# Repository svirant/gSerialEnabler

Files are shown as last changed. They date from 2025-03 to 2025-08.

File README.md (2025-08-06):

# gSerial Enabler
**"plug-n-play" gcomp/gscart EXT adapter that enables auto-profiles for the RetroTink 4K**

 - A powered-on console on port 1-8 will load SVS profiles S201_ - S208_ on the RT4K Pro/CE
 - Compatible with the SVS
 - Connect multiple gSerial Enablers, Donut Holes, Donut Dongles simultaneously via a headphone jack splitter.
   - Must reflash "firmware" with offset variable set so SVS profile numbers don't overlap.
   - Ex: offset = 8, adds 8 to the default of 201. So ports 1 - 8 would now be S209_ - S216_
   - Up to 5 have been connected together simultaneously. More may be supported, but this is the max number I've been able to test.
 - Full instructions listed below for building your own!
 - If DIY is not your thing, I also have a handful assembled and available for purchase on [Ko-fi](https://ko-fi.com/donutswdad/shop)

> [!NOTE]
> The EXT port does not exist on all gscart/gcomp revisions. Make sure your switch has one! There are now 2 versions available.
>  - "Internal" is for EXT with no header. (exposed through-holes)
>  - "External" is for EXT with right angle header populating the port.
</br>

Thanks to Bob [@RetroRGB](https://www.retrorgb.com/) for showcasing!</br>
Thanks Bob (https://www.youtube.com/watch?v=3wcF-8wC7H4&t=119s)
Thanks Bob (https://www.youtube.com/watch?v=b-BxFDCHc2k&t=1107s)

# Internal
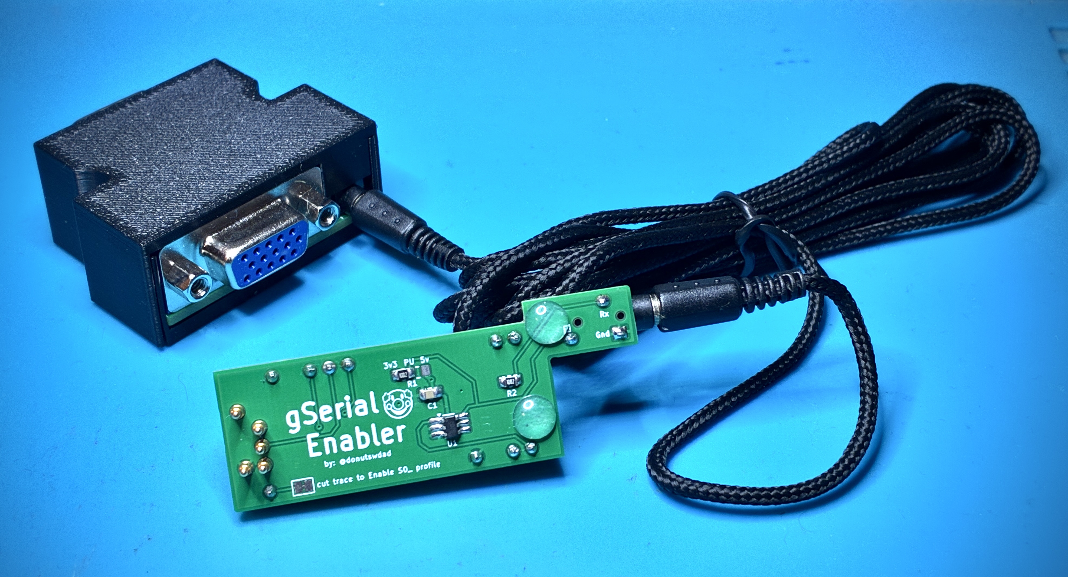
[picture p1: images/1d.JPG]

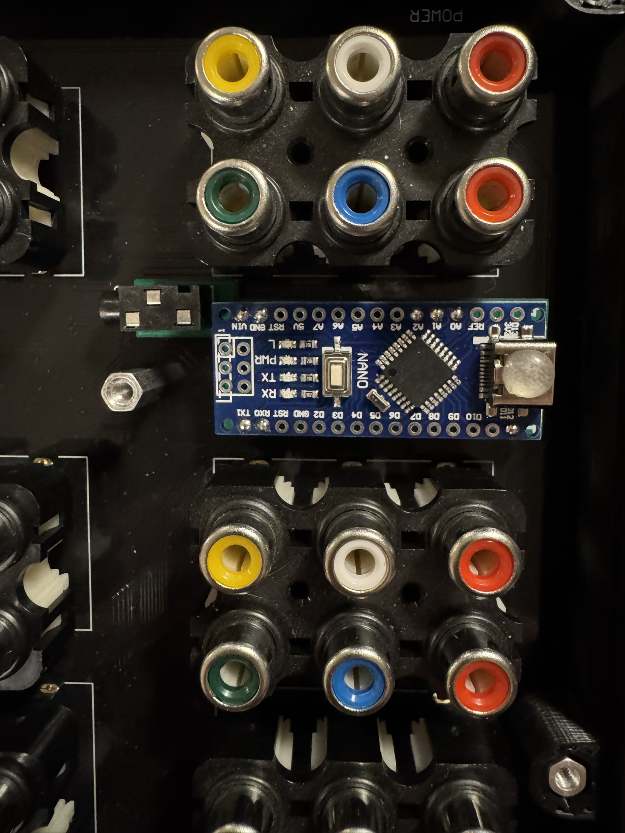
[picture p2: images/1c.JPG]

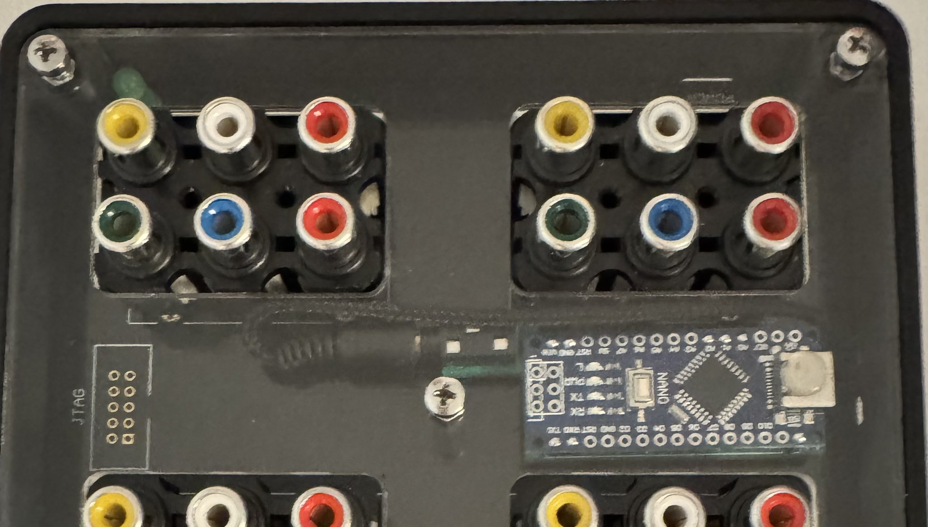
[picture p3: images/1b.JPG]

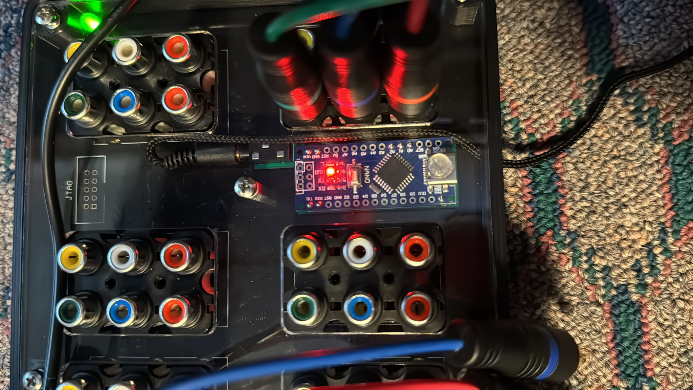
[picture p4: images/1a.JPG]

<br />
<br />

# External
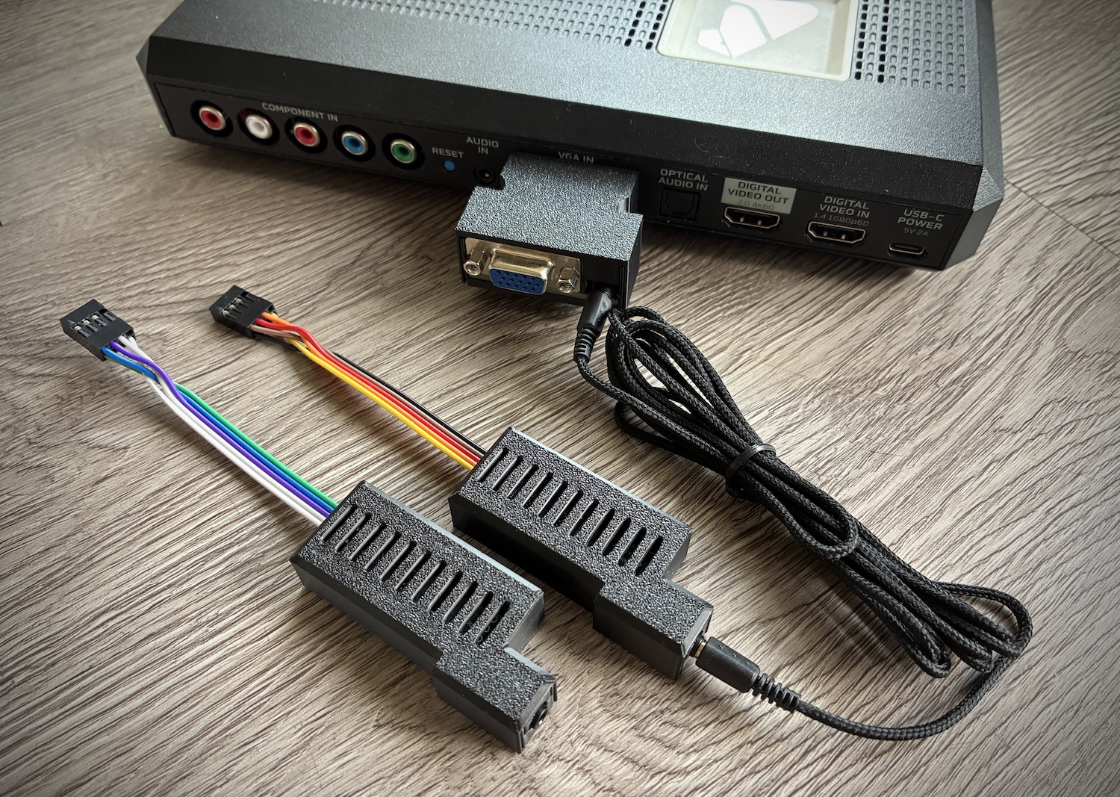
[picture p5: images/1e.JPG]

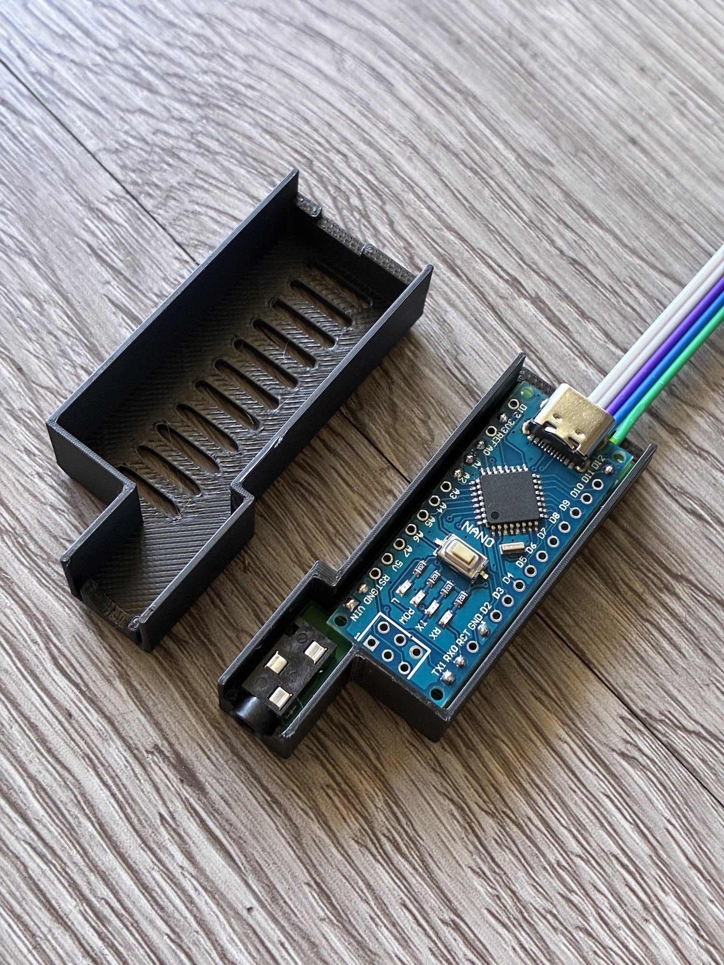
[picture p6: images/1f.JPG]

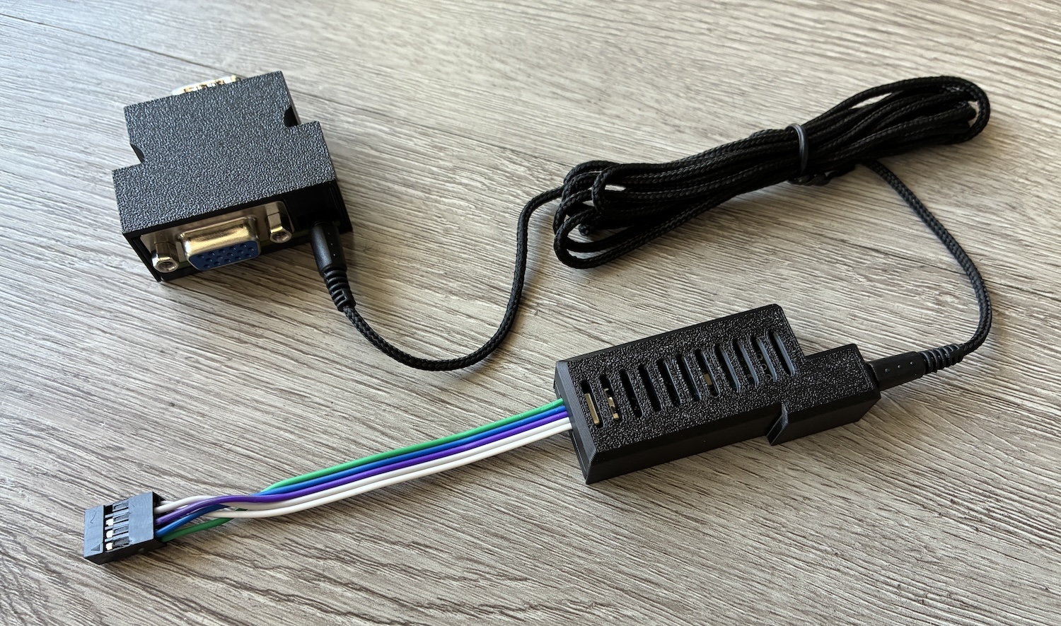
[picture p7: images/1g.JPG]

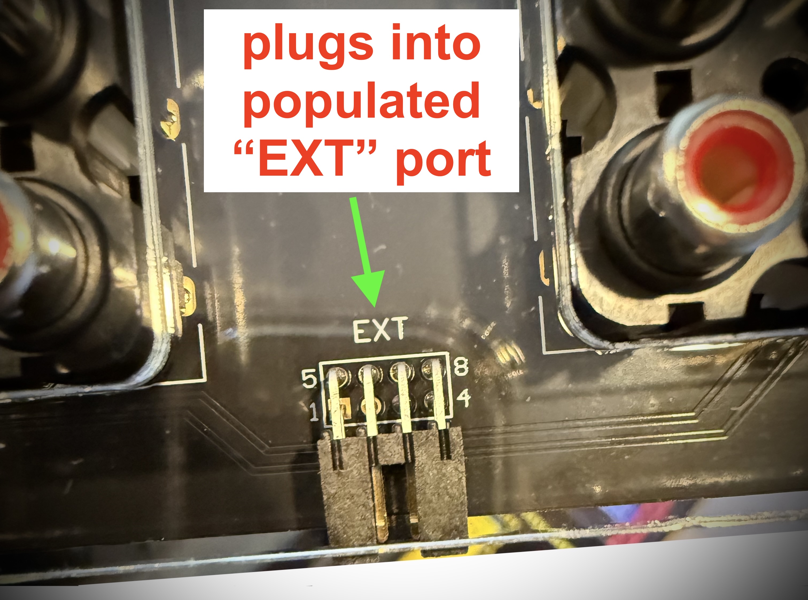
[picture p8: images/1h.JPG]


# Conversion!
> [!TIP]
>  - If you wanted to use the External version on your headerless gcomp/gscart, you can easily solder a 2.54mm DC3 angled header onto the EXT port. Part listed in BOM below.
</br>

# Thanks to 
   - **[@UstSte](https://x.com/UstSte) for the photos and testing.**

   - **[Bob](https://twitter.com/retrorgb) @ [RetroRGB](https://www.retrorgb.com/retrotink-4k-firmware-v1-6-9-released.html) for his ideas and continued support.**

<br />
<br />

# Ordering PCBs
PCBs for this project:
 - [gSerial Enabler (Internal)](https://github.com/svirant/gSerialEnabler/blob/main/gSerial_Enabler.zip)
 - [gSerial Enabler (External)](https://github.com/svirant/gSerialEnabler/blob/main/gSerial_Enabler_External.zip)
    - [3DP Case (External)](https://github.com/svirant/gSerialEnabler/blob/main/gSerial_Enabler.3mf)
 - [VGA Adapter](https://github.com/svirant/DonutDongle/tree/main/Adapters) (VGAPassthrough or YC2VGA)
</br>

> [!NOTE]
> The "Internal" PCB can also be used for the "External" build. Only the through-holes are smaller. The through-holes have been made larger on the External version to make soldering the Dupont line easier.
> It should be noted that the reverse is not true. The through-holes on the External version are too big to properly secure to pogo-pins.
>

</br>

There are plenty of options for PCB manufacturing but I prefer [JLCPCB](https://jlcpcb.com) (No affiliation). Using the gerber (.zip) files provided, it's easy to place an order. Below are some tips/guidelines:
- 1.6mm Thickness
- For Surface Finish, "HASL(with lead)" is fine
- 4 Layer PCBs are the same cost as 2 Layer for the VGA Adapters. Because of that, the inner 2 layers are being used as ground planes for better EMI protection. Thanks to https://x.com/zaxour for the idea!
- "Remove Mark" option is now free on JLCPCB. Use it!
- All remaining default options should be fine
- Let me know if you have any questions!

# Assembly

[Interactive HTML BOM](https://svirant.github.io/gSerialEnabler/images/ibom.html)

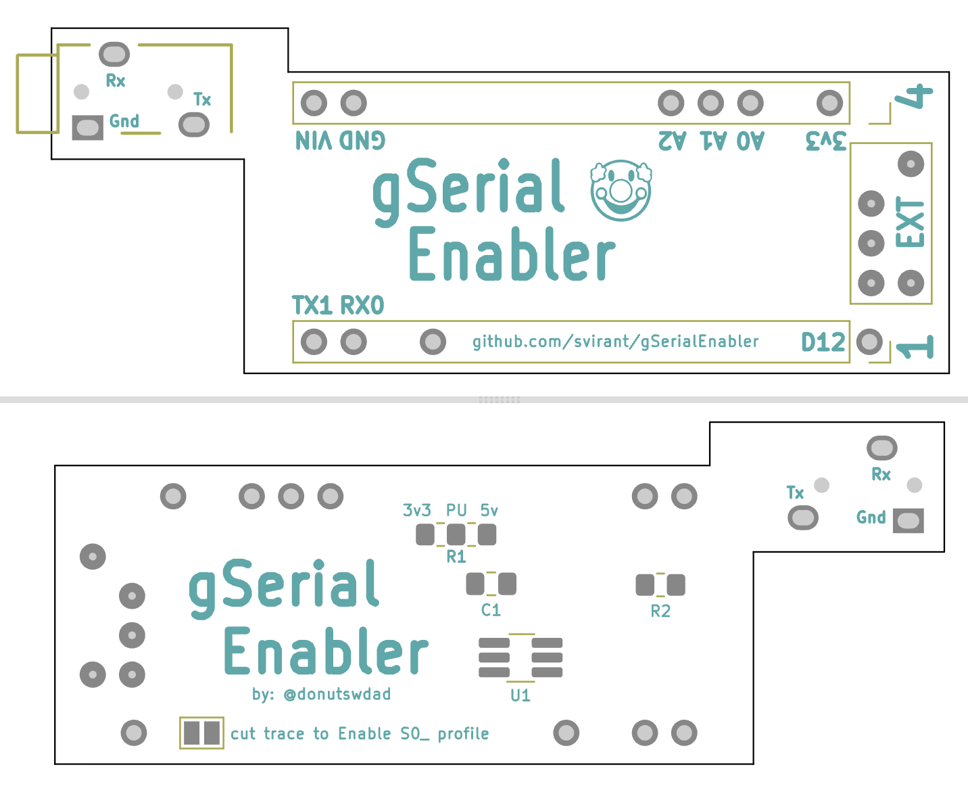
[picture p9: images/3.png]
[](https://svirant.github.io/gSerialEnabler/images/ibom.html)

## Internal assembly
In addition to the top of the usb-c port, place two more 6x2mm rubber feet to the spots shown, to secure the PCB.

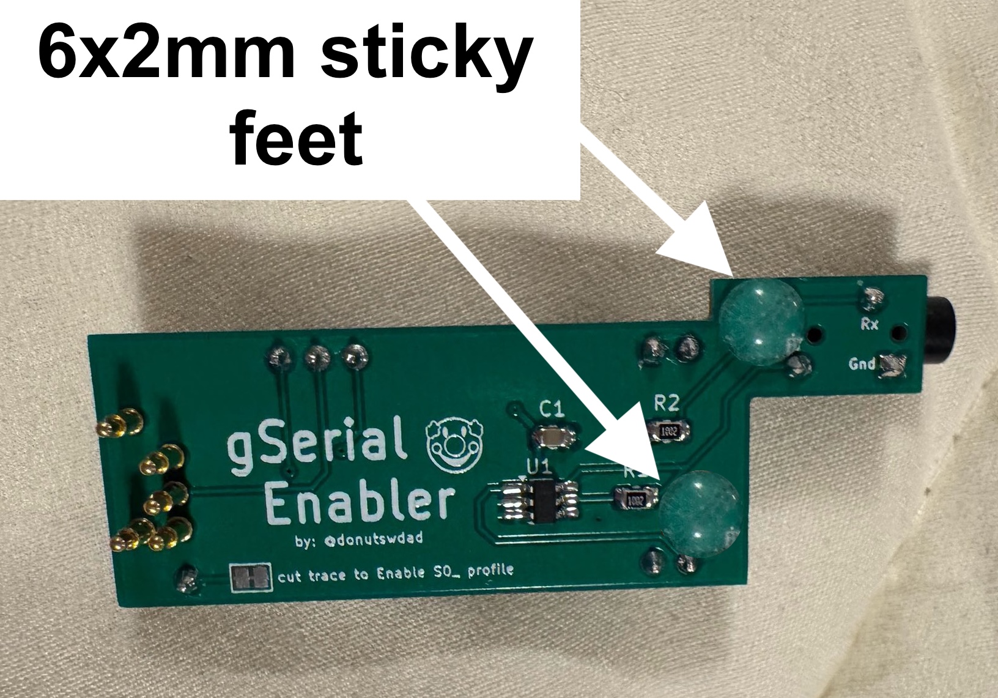
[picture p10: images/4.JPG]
 </br>

## External assembly
 - Cut Dupont line in half for 10cm section. 
 - Remove plastic covers on Dupont line and insert into 2x4 Dupont shell as shown below.
 - Strip wire on other end and solder into through-holes on PCB.

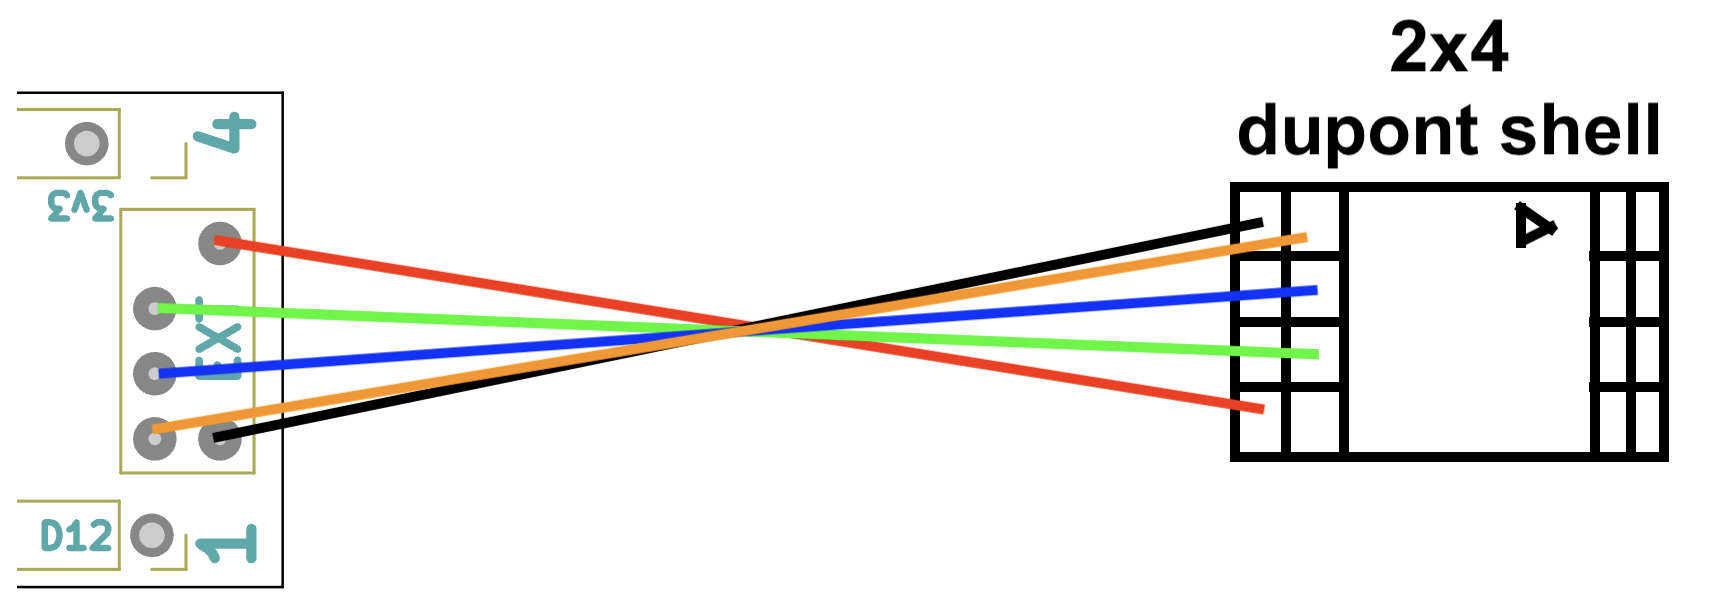
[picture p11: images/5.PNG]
 </br>

# PCB
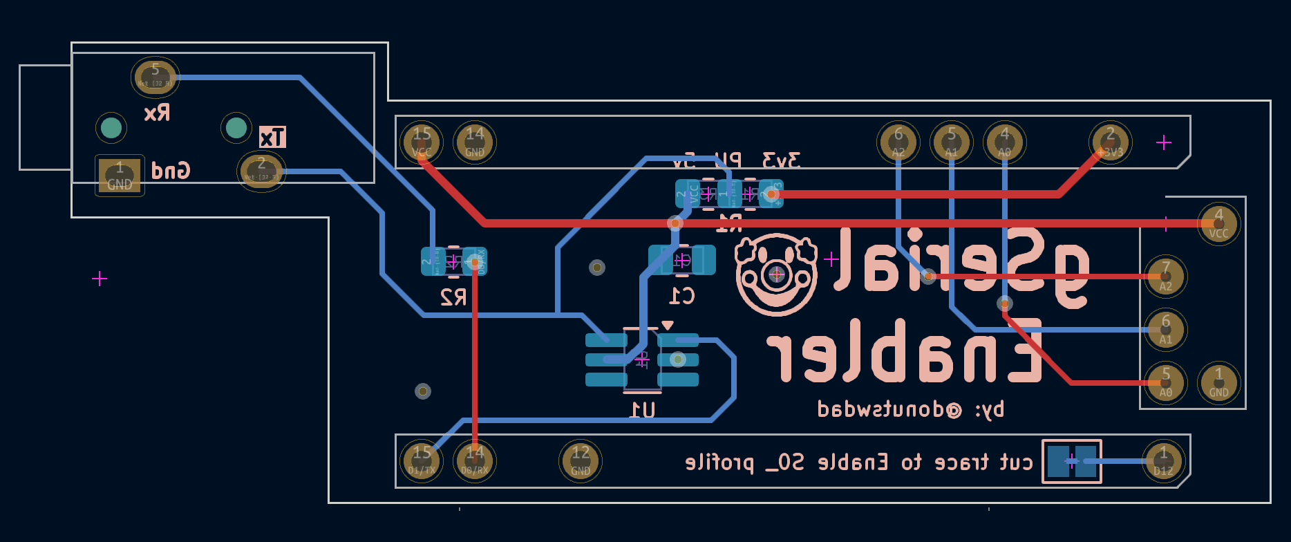
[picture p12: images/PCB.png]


# Schematic
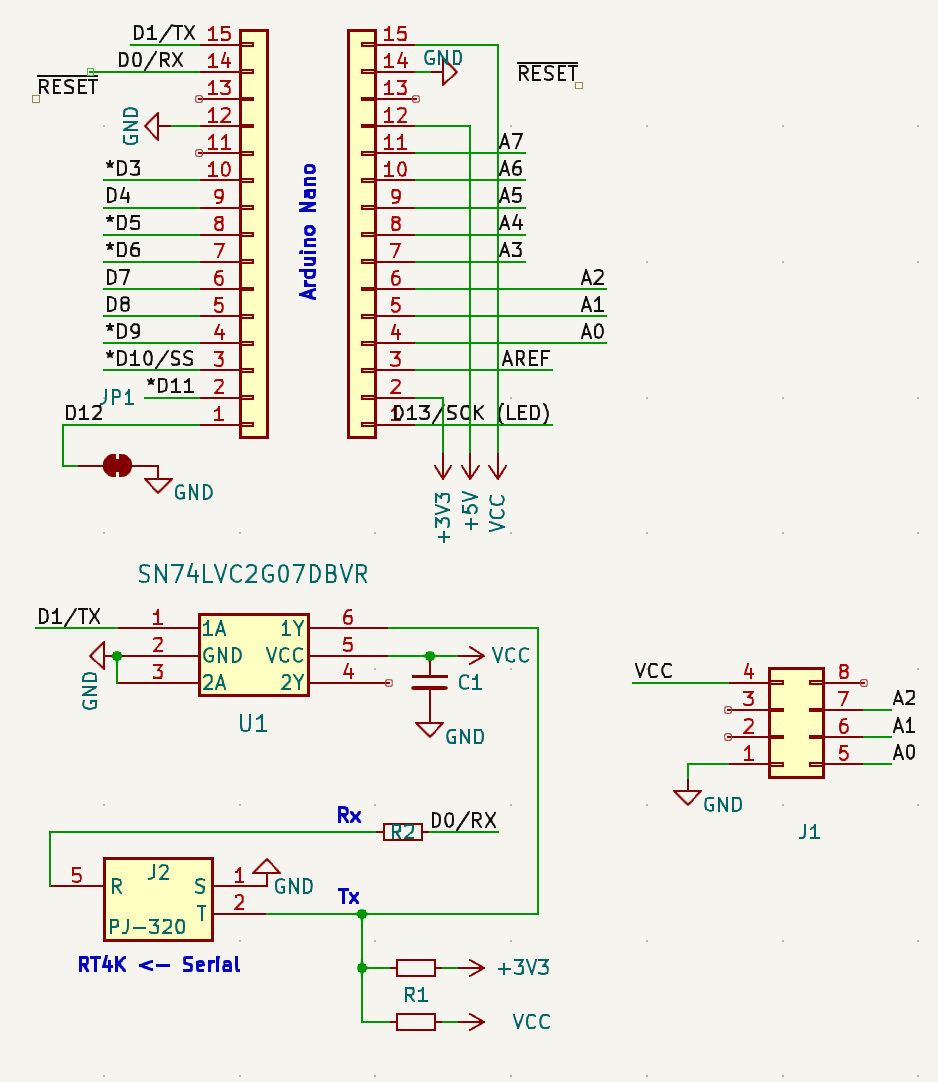
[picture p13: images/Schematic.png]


## Bill of Materials (BOM)

### * gSerial Enabler
| **Qty** | Designation | Part |  Link  |  Notes |
| --- | --- |--- |--- |--- |
| 1  | C1 | 0.1 uf / 100nf 50V X7R 0805 Capacitor| [Digikey](https://www.digikey.com/en/products/detail/yageo/CC0805KRX7R9BB104/302874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) | |
| 2  | R1, R2 | 10K OHM 1% 1/8W 0805 Resistor | [Digikey](https://www.digikey.com/en/products/detail/yageo/AC0805FR-0710KL/2827834) | |
| 1  | U1 | IC BUF NON-INVERT 5.5V SOT23-6 | [Digikey](https://www.digikey.com/en/products/detail/texas-instruments/SN74LVC2G07DBVR/486427) or [alternate](https://www.digikey.com/en/products/detail/umw/SN74LVC2G07DBVR/24889644) | |
| 1  | J2 | PJ-320 3.5MM Headphone Jack Audio Video Female | [AliExpress](https://www.aliexpress.us/item/3256807448104402.html) | Color: PJ-320B DIP | 
| 10  | J3,J4 | 2.54mm male pin headers | break off the male headers that come with the Arduino Nano | | 
| 1  | | Arduino Nano type c | Support [RetroRGB!](https://amzn.to/4gnHqN4) | Make sure the headers are not soldered. |
| 1  | | Any 3.5mm / aux / stereo / trs / cable | [AliExpress](https://www.aliexpress.us/item/2255799962255486.html) | I prefer the one listed because the cable itself is very flexible and has no problem being routed inside the case.|
| 1  | | usb-c cable for Arduino programming | [AliExpress](https://www.aliexpress.us/item/3256806983355947.html) | |
| 3 | | 6x2mm sticky rubber feet | [Amazon](https://www.amazon.com/dp/B06XCNM69B)| Internal version only |
| 5 | Pogo-Pin | Mill-Max 0906-1-15-20-75-14-11-0 | [Digikey](https://www.digikey.com/en/products/detail/mill-max-manufacturing-corp/0906-1-15-20-75-14-11-0/1147049) | Internal version only |
| 1 | 2x4 Dupont shell | Pins: 2x4Pin | [AliExpress](https://www.aliexpress.us/item/2255800942949805.html) | External version only | 
| 1 | Dupont line 20cm | Color: Female to Female | [AliExpress](https://www.aliexpress.us/item/3256805315188857.html) | External version only |
| 1 | CONN HEADER R/A 8POS 2.54MM | Part# 78207-108HLF | [Digikey](https://www.digikey.com/en/products/detail/amphenol-cs-fci/78207-108HLF/1002752) | (Optional) If you wanted to use the External version on your headerless gcomp/gscart, you can solder this part on. |
| 1 | Alt to the official header above | Color: Right Angle Type , Pins: 8P | [AliExpress](https://www.aliexpress.us/item/3256805058042964.html) | Will most likely not fit inside the LaserBear bumper case, not confirmed. Just FYI. |

### * VGA Adapter assembly and BOM can be found [here](https://github.com/svirant/DonutDongle?tab=readme-ov-file#at-least-1-of-the-following-vga-adapters-is-required)
<br />

# Programming an Arduino Nano
I recommend the [Official Arduino IDE and guide](https://www.arduino.cc/en/Guide) if you're unfamiliar with Arduinos. All .ino files used for programming are listed above. 

Some Arduino Nanos come with an Old Bootloader and won't Upload unless specified. **If you get errors** when trying to upload, swap to this option as a possible fix.

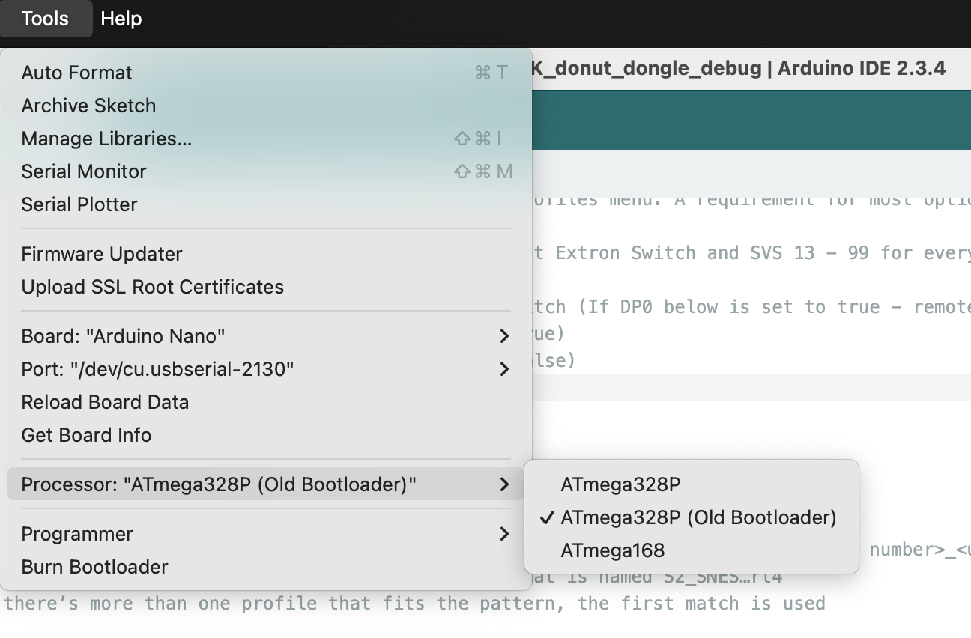
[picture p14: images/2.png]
bootloader


## Steps to update offset
 - 1 - Download and install the [Arduino IDE](https://www.arduino.cc/en/software/) for your PC or Mac
 - 2 - Click the green "<> Code" button above and "Download ZIP".
 - 3 - Extract the .zip file and open up the "gSerial_Enabler.ino" file in the Arduino IDE. It will ask if you would like to move this file inside a folder, select OK.
 - 4 - With the source code now open, select "Tools" -> "Board" -> "Arduino AVR Boards" -> "Arduino Nano"
 - 5 - Connect the gSerial Enabler device to your PC or Mac using a usb-c cable. You should see an LED light up when connected.
   - If connecting the "External" version, you must remove the top half of the case by sliding it upwards while holding parts beneath the aux jack on one side and ribbon cable on other. This will expose the usb-c port.
   - If connecting the "Internal" version, it's okay to flash it while still inside the gscart/gcomp. Just disconnect power from the gscart/gcomp first.
 - 6 - With the gSerial Enabler now connected, select it's "port" by going to "Tools" -> "Port", and select the port that starts with "/dev/cu.usbserial-" (on Mac) or "COM" if on PC.
 - 7 - Almost done! :) In the code itself, find the line that starts with "uint16_t const offset = 0;" and change the 0 to an 8. It should now look like this: uint16_t const offset = 8;
   - At the moment this is line 27
 - 8 - From the menu at the top, select "Sketch" -> "Upload". You should see the LEDs on the Arduino Nano flicker and a message that says "Done uploading." if successful.
    - If you get errors, see the section above about changing the "Bootloader" type.
 - 9 - Disconnect the usb-c cable and give it a whirl! You can repeat these steps in the future to make any other changes or update if a newer firmware is ever released.
  -----------
# How to Use
- Make sure **"Auto Load SVS"** is **"On"** under the RT4K Profiles menu.  
- The RT4K checks the **/profile/SVS** subfolder for profiles and need to be named: **S\<input number>_\<user defined>.rt4**  For example, SVS input 201 would look for a profile that is named S201_SNES.rt4.  If there’s more than one profile that fits the pattern, the first match is used.

- Check the RT4K Diagnostic Console for Serial commands being received as confirmation.

## SVS Profile numbering scheme

**Ports 1-8 = S201\_ - S208\_**

The "offset" option can be used if using multiple gSerial Enablers connected to the RT4K via a headphone splitter. If using a 2nd, change to "offset = 8" for the 2nd to be SVS profiles 209 - 216.

```
uint16_t const offset = 0; // Only needed for multiple gSerial Enablers. Set offset so 2nd, 3rd, etc gSEs don't overlap profiles. (e.g. offset = 8;) 
```

## S0_ profile Enable

By cutting the trace on the PCB, you can enable the S0_ profile which will load S0_\<whatever\>.rt4 when all inputs are off. If you wish to revert the change, you can bridge the trace with a solder blob. 

Instead of cutting the trace, you can also change line 29 of the gSerial_Enalber.ino to "true" for the same functionality. ...Assuming you are able to program the Arduino Nano with the updated .ino. Up to you which method to choose.

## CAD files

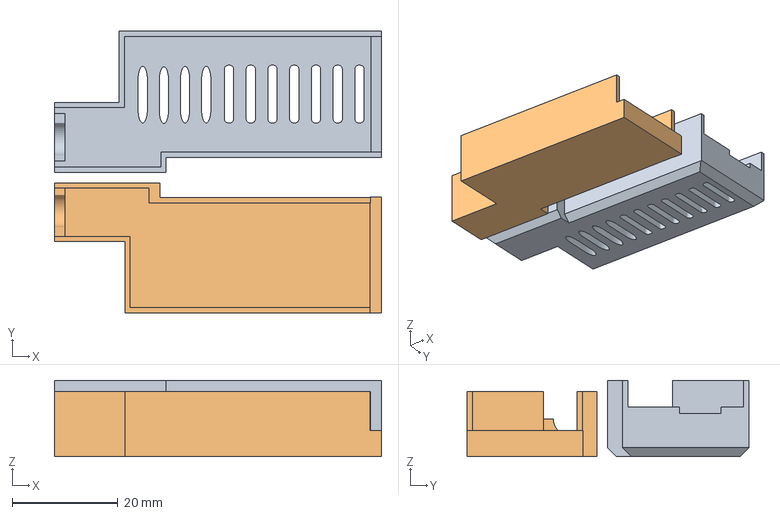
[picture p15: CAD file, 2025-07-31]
gSerial_Enabler.3mf
61.8 x 53.3 x 14.4 mm
gSerialEnabler_T2.stl
gSerialEnabler_Bottom.stl

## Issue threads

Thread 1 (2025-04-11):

Chance for Extron Crosspoint Ultra Version?

aaaaafuck, 2025-04-11:
Is there any chance we can see a version of this that works with an Extron Crosspoint Ultra as apposed to the Gswitches? I believe they have some sort of serial adapter on the rear of the unit, but I could be wrong as to what that is for. There may also be a way to use the lan port to determine what preset is selected.

svirant, 2025-04-11:
Howdy! There are 2 projects I have that can talk to a handful of Extron switches and even TESmart/MK-VIKI HDMI switches.

[Donut Dongle](https://github.com/svirant/DonutDongle)
[Donut Hole](https://github.com/svirant/DonutHole)

There are currently some Donut Dongles made by another user for sale on the RetroTink Discord Classified section.  I don't have any plans to make these as they are very time consuming, but I do plan on making some of the "Donut Hole" devices soon...

Closed 2025-04-11.

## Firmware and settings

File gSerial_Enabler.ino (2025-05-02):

/*
* gSerial Enabler v0.4
* Copyright (C) 2025 @Donutswdad
*
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
* You should have received a copy of the GNU General Public License
* along with this program.  If not, see <http://www.gnu.org/licenses/>.
*/

/*
////////////////////
//    OPTIONS    //
//////////////////
*/

uint8_t debugG = 0; // line ~180

uint16_t const offset = 0; // Only needed if multiple Donut Holes, gSerial Enablers, Donut Dongles are connected. Set offset so 2nd, 3rd, etc don't overlap profiles. (e.g. offset = 8;) 

bool S0 = false;           // (Profile 0) 
                           //  ** Recommended to leave this option "false" if using in tandem with other Serial devices. ** (Leave JP1 trace un-cut)

////////////////////
                       
// gscart / gcomp adjustment variables for port detection
float const highsamvolt = 2.4; // rise above this voltage for a high sample
byte const apin[3] = {A0,A1,A2}; // defines analog pins used to read bit0, bit1, bit2 respectively
uint8_t const dch = 15; // (duty cycle high) at least this many high samples per "samsize" for a high bit (~75% duty cycle)
uint8_t const dcl = 5; // (duty cycle low) at least this many high samples and less than "dch" per "samsize" indicate all inputs are in-active (~50% duty cycle)
uint8_t const samsize = 20; // total number of ADC samples required to capture at least 1 period
uint8_t const fpdccountmax = 3; // number of periods required when in the 50% duty cycle state before a Profile 0 is triggered.


// gscart / gcomp Global variables
uint8_t fpdcprev = 0; // stores 50% duty cycle detection
uint8_t fpdccount = 0; // number of times a 50% duty cycle period has been detected
uint8_t allgscartoff = 2; // 0 = at least 1 port is active, 1 = no ports are active, 2 = disconnected or not used yet
uint8_t samcc = 0; // ADC sample cycle counter
uint8_t highcount[3] = {0,0,0}; // number of high samples recorded for bit0, bit1, bit2
uint8_t bitprev[3] = {0,0,0}; // stores previous bit state


void setup(){

    Serial.begin(9600); // set the baud rate for the RT4K Serial Connection
    pinMode(A2,INPUT); // set A2 as bit2 input
    pinMode(A1,INPUT); // set A1 as bit1 input
    pinMode(A0,INPUT); // set A0 as bit0 input
    pinMode(12,INPUT_PULLUP);
    delay(100);
    if(digitalRead(12) == HIGH) S0 = true; // check state of JP1 jumper

} // end of setup

void loop(){

  readGscart(); // reads A0,A1,A2 pins to see which port, if any, are active

} // end of loop()

void readGscart(){

  // https://shmups.system11.org/viewtopic.php?p=1307320#p1307320
  // gscartsw_lite EXT pinout:
  // Pin 1: GND
  // Pin 2: Override
  // Pin 3: N/C
  // Pin 4: +5V
  // Pin 5: IN_BIT0
  // Pin 6: IN_BIT1
  // Pin 7: IN_BIT2
  // Pin 8: N/C
  //
  // Reference for no active input state: https://shmups.system11.org/viewtopic.php?t=50851&start=4976
  //
  // When no input is active, a 50% off/on cycle can be seen for each pin as it cycles through the inputs. Pin5 the fastest, Pin7 the slowest. If we can monitor each
  // pin then we can detect when there is no active input.
  //
  //        Pin7 Pin6 Pin5
  // Port1  0     0     0
  // Port2  0     0     1
  // Port3  0     1     0
  // Port4  0     1     1 
  // Port5  1     0     0
  // Port6  1     0     1
  // Port7  1     1     0
  // Port8  1     1     1

  uint8_t fpdc = 0; // 1 = 50% duty cycle was detected / all ports are in-active
  uint8_t bit[3] = {0,0,0};
  float val[3] = {0,0,0};
  
  for(uint8_t i = 0;i < 3; i++){ // read in analog pin voltages, read each pin 4x in a row to ensure an accurate read, combats if using too large of a pull-down resistor
    for(uint8_t j = 0;j < 4; j++){
      val[i] = analogRead(apin[i]);
    }
    if((val[i]/211) >= highsamvolt){ // if voltage is greater than or equal to the voltage defined for a high, increase highcount by 1 for that analog pin
      highcount[i]++;
    }
  }

  if(samcc == samsize){               // when the "samsize" number of samples has been taken, if the voltage was "high" for more than "dch" # of the "samsize" samples, set the bit to 1
    for(uint8_t i = 0;i < 3; i++){
      if(highcount[i] > dch)          // if the number of "high" samples per "samsize" are greater than "dch" set bit to 1.  
        bit[i] = 1;
      else if(highcount[i] > dcl)     // if the number of "high" samples is greater than "dcl" and less than "dch" (50% high samples) the switch must be cycling inputs, therefor no active input
        fpdc = 1;
    }
  }


  if(((bit[2] != bitprev[2] || bit[1] != bitprev[1] || bit[0] != bitprev[0]) || (allgscartoff > 0)) && (samcc == samsize) && !(fpdc)){
    //Detect which scart port is now active and change profile accordingly
    if((bit[2] == 0) && (bit[1] == 0) && (bit[0] == 0)){ // 0 0 0
      sendSVS(201);
    } 
    else if((bit[2] == 0) && (bit[1] == 0) && (bit[0] == 1)){ // 0 0 1
      sendSVS(202);
    }
    else if((bit[2] == 0) && (bit[1] == 1) && (bit[0] == 0)){ // 0 1 0
      sendSVS(203);
    }
    else if((bit[2] == 0) && (bit[1] == 1) && (bit[0] == 1)){ // 0 1 1
      sendSVS(204);
    }
    else if((bit[2] == 1) && (bit[1] == 0) && (bit[0] == 0)){ // 1 0 0
      sendSVS(205);
    } 
    else if((bit[2] == 1) && (bit[1] == 0) && (bit[0] == 1)){ // 1 0 1
      sendSVS(206);
    }   
    else if((bit[2] == 1) && (bit[1] == 1) && (bit[0] == 0)){ // 1 1 0
      sendSVS(207);
    } 
    else if((bit[2] == 1) && (bit[1] == 1) && (bit[0] == 1)){ // 1 1 1
      sendSVS(208);
    }
    
    if(allgscartoff) allgscartoff = 0;
    bitprev[0] = bit[0];
    bitprev[1] = bit[1];
    bitprev[2] = bit[2];
    fpdcprev = fpdc;

  }


  if((fpdccount == (fpdccountmax - 1)) && (fpdc != fpdcprev) && (samcc == samsize)){ // if no active port has been detected for fpdccountmax periods
    
    allgscartoff = 1;
    memset(bitprev,0,sizeof(bitprev));
    fpdcprev = fpdc;

    if(S0){ // if trace has been cut, load S0_ SVS profile
      sendSVS(0);
    }

  }


  if(fpdc && (samcc == samsize)){ // if no active port has been detected, loop counter until active port
    if(fpdccount == (fpdccountmax - 1))
      fpdccount = 0;
    else 
      fpdccount++;
  }
  else if(samcc == samsize){
    fpdccount = 0;
  }

  if(debugG){ // debug
    delay(200);
    Serial.print(F("A0 voltage:         "));Serial.println(val[0]/211);
    Serial.print(F("A1 voltage:         "));Serial.println(val[1]/211);
    Serial.print(F("A2 voltage:         "));Serial.println(val[2]/211);
  }

  if(samcc < samsize) // increment counter until "samsize" has been reached then reset counter and "highcount"
    samcc++;
  else{
    samcc = 1;
    memset(highcount,0,sizeof(highcount));
  }

} // end readGscart()

void sendSVS(uint16_t num){
  Serial.print(F("\rSVS NEW INPUT="));
  Serial.print(num + offset);
  Serial.println(F("\r"));
  delay(1000);
  Serial.print(F("\rSVS CURRENT INPUT="));
  Serial.print(num + offset);
  Serial.println(F("\r"));
}

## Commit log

2025-03-17 PCB gerber
2025-03-17 update BOM
2025-03-19 fix BOM
2025-03-20 added "return" character before every serial command to clear out buffer. needed when sharing TX bus with other devices.
2025-03-24 fixed S0_ profile issue when "offset" is used
    [gSerial_Enabler.ino]
2025-03-25 fixed bug in S0_ and S201_ transition
    [gSerial_Enabler.ino]
2025-04-02 updated BOM
2025-04-06 added ko-fi link for assembled units
2025-04-06 added link to VGA adapter assembly and BOM
2025-05-02 Compatibility fix for gscart VGA v3.4 switches. lowered "high" bit detection to 2.4v for a high vs 3.1v.
    [gSerial_Enabler.ino]
2025-07-31 added info for new External version
    [gSerial_Enabler.3mf]
2025-07-31 added external assembly wiring diagram
2025-07-31 added note about Internal vs External PCB differences
2025-08-04 added official EXT header used on new gswitches to BOM
2025-09-16 does not appear to work on older gscart versions 1.1. bit pins stay at high voltage regardless of active input.
2025-11-06 incorrect version of gscartsw_lite was listed to not be currently compatible

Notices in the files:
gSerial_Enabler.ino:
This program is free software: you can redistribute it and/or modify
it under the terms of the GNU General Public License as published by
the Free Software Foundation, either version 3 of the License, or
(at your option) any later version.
